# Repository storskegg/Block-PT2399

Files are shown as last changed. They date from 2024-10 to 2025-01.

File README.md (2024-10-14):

# Block-PT2399

A simple delay/echo design block based on the venerable PTC PT2399.

## Features

- Star Grounds: This board features a 2-star ground configuration
    1. All ground connections from and relating directly to the PT2399, and its
       dedicated power supply (`7805`) have their own trace to the negative lead
       on the `7805`'s `100uF` bypass capacitor.
    2. The above ground star, and all other ground connections (e.g. JFET
       impedance buffer) have their own traces back to `Sig_gnd`.
- Onboard regulation: The PT2399 is a particularly noisy beast, and must have
  its own power rail. As such, this board has its own 7805 regulator, and bypass
  capacitor (`100uF` located as close to the PT2399 as possible, while
  facilitating the star ground to the chip's supporting circuitry, and mfr's
  fabrication constraints.)

## Background

I've been working on a blues harp preamp for a buddy, and have been working on
the design in logical blocks that more or less get strung together. (It makes a
lot of sense when looking at valve gain stages, which are all basically the same
circuit repeated, maybe with different component values.) He mentioned wanting
delay or echo, and so I put this together. It is not a ground-up design, but
rather one that was inspired by the countless examples of using the PT2399
that you can find in the wild. (Sometimes it's better to stand on the shoulders
of giants.)

Anyhow, I decided to do up a board for ease of use in future projects.

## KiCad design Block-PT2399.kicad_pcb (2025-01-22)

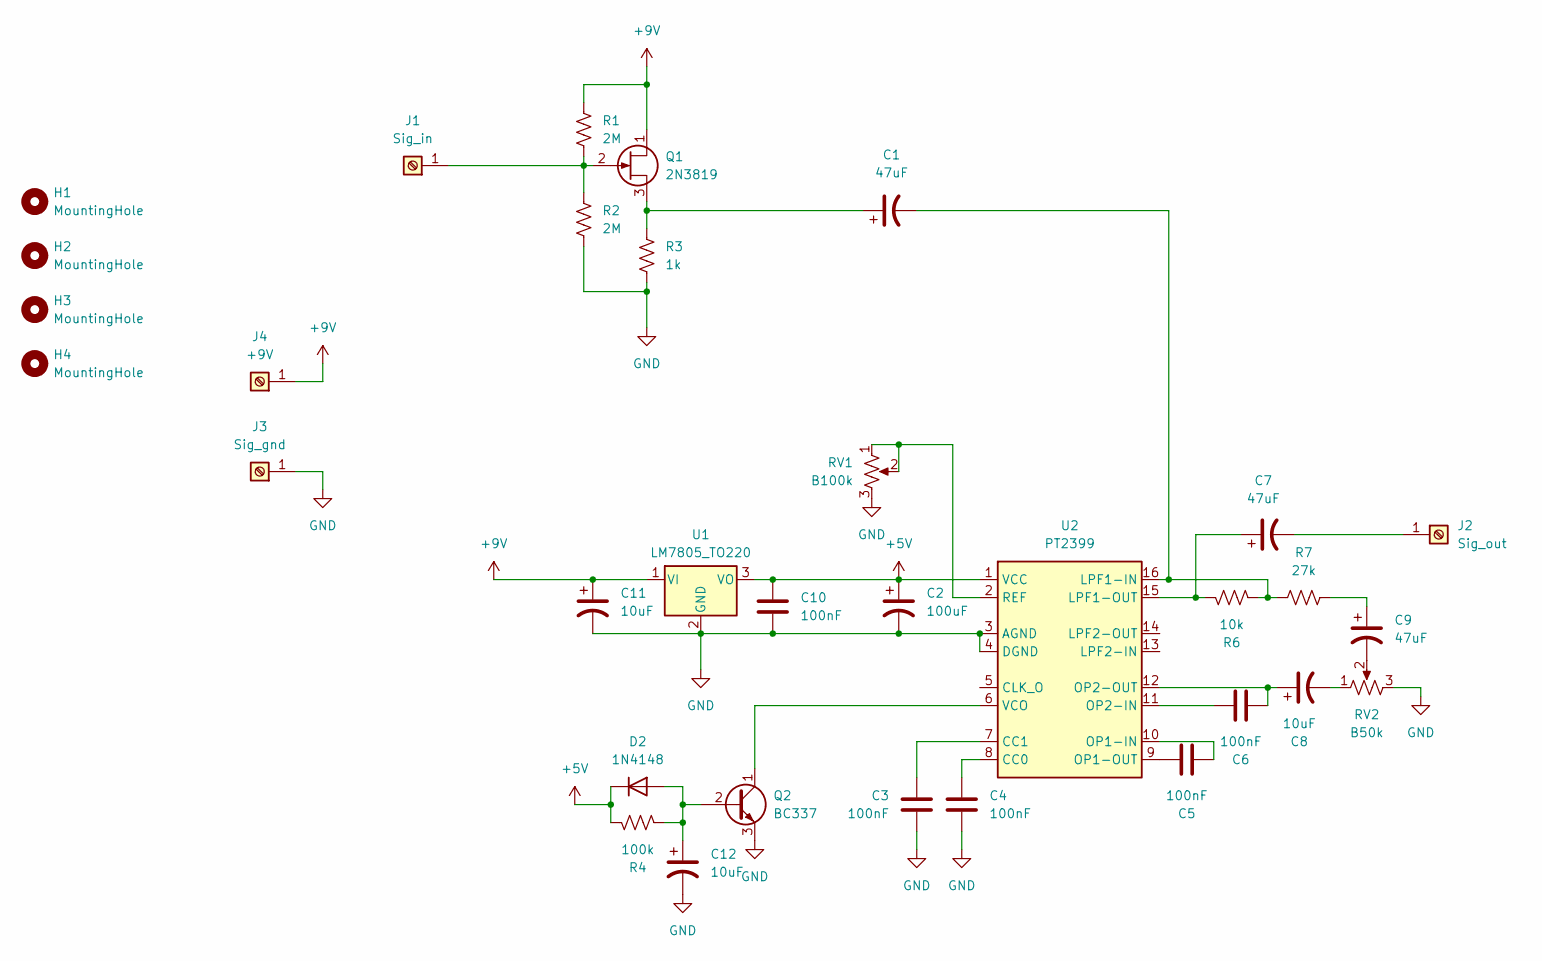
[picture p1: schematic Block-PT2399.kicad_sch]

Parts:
C1, C7, C9: 47uF; CP_Radial_D5.0mm_P2.00mm
C2: 100uF; CP_Radial_D5.0mm_P2.50mm
C3, C4, C5, C6: 100nF; C_Disc_D4.3mm_W1.9mm_P5.00mm
C8: 10uF; CP_Radial_D4.0mm_P1.50mm
C10: 100nF; C_Disc_D3.0mm_W1.6mm_P2.50mm
C11: 10uF; CP_Radial_D5.0mm_P2.00mm
C12: 10uF; CP_Radial_D4.0mm_P2.00mm
D2: 1N4148; D_DO-35_SOD27_P7.62mm_Horizontal
H1, H2, H3, H4: MountingHole; MountingHole_2.2mm_M2
J1: Sig_in; TerminalBlock_MetzConnect_360271_1x01_Horizontal_ScrewM3.0_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
J2: Sig_out; TerminalBlock_MetzConnect_360271_1x01_Horizontal_ScrewM3.0_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
J3: Sig_gnd; TerminalBlock_MetzConnect_360271_1x01_Horizontal_ScrewM3.0_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
J4: +9V; TerminalBlock_MetzConnect_360271_1x01_Horizontal_ScrewM3.0_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
Q1: 2N3819; TO-92_Inline_Wide
Q2: BC337; TO-92_Inline
R1, R2: 2M; R_Axial_DIN0207_L6.3mm_D2.5mm_P10.16mm_Horizontal
R3: 1k; R_Axial_DIN0207_L6.3mm_D2.5mm_P10.16mm_Horizontal
R4: 100k; R_Axial_DIN0204_L3.6mm_D1.6mm_P5.08mm_Horizontal
R6: 10k; R_Axial_DIN0207_L6.3mm_D2.5mm_P10.16mm_Horizontal
R7: 27k; R_Axial_DIN0207_L6.3mm_D2.5mm_P10.16mm_Horizontal
RV1: B100k; Potentiometer_Bourns_3266Y_Vertical
RV2: B50k; Potentiometer_Bourns_3266Y_Vertical
U1: LM7805_TO220; TO-220-3_Vertical
U2: PT2399; DIP-16_W7.62mm

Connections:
+5V: C2.1, C10.1, D2.1 (K), R4.2, U1.3 (VO), U2.1 (VCC)
+9V: C11.1, J4.1, Q1.1 (D), R1.1, U1.1 (VI)
GND: C2.2, C3.2, C4.2, C10.2, C11.2, C12.2, J3.1, Q2.3 (E), R2.2, R3.2, RV1.3, RV2.3, U1.2 (GND), U2.3 (AGND), U2.4 (DGND)
unnamed: C8.2, RV2.1
unnamed: C9.1, R7.2
unnamed: C9.2, RV2.2
unnamed: C12.1, D2.2 (A), Q2.2 (B), R4.1
unnamed: J1.1, Q1.2 (G), R1.2, R2.1
unnamed: C7.2, J2.1
unnamed: C1.1, Q1.3 (S), R3.1
unnamed: Q2.1 (C), U2.6 (VCO)
unnamed: C4.1, U2.8 (CC0)
unnamed: C3.1, U2.7 (CC1)
unnamed: C1.2, R6.2, R7.1, U2.16 (LPF1-IN)
unnamed: C7.1, R6.1, U2.15 (LPF1-OUT)
unnamed: C5.1, U2.10 (OP1-IN)
unnamed: C5.2, U2.9 (OP1-OUT)
unnamed: C6.1, U2.11 (OP2-IN)
unnamed: C6.2, C8.1, U2.12 (OP2-OUT)
unnamed: RV1.1, RV1.2, U2.2 (REF)

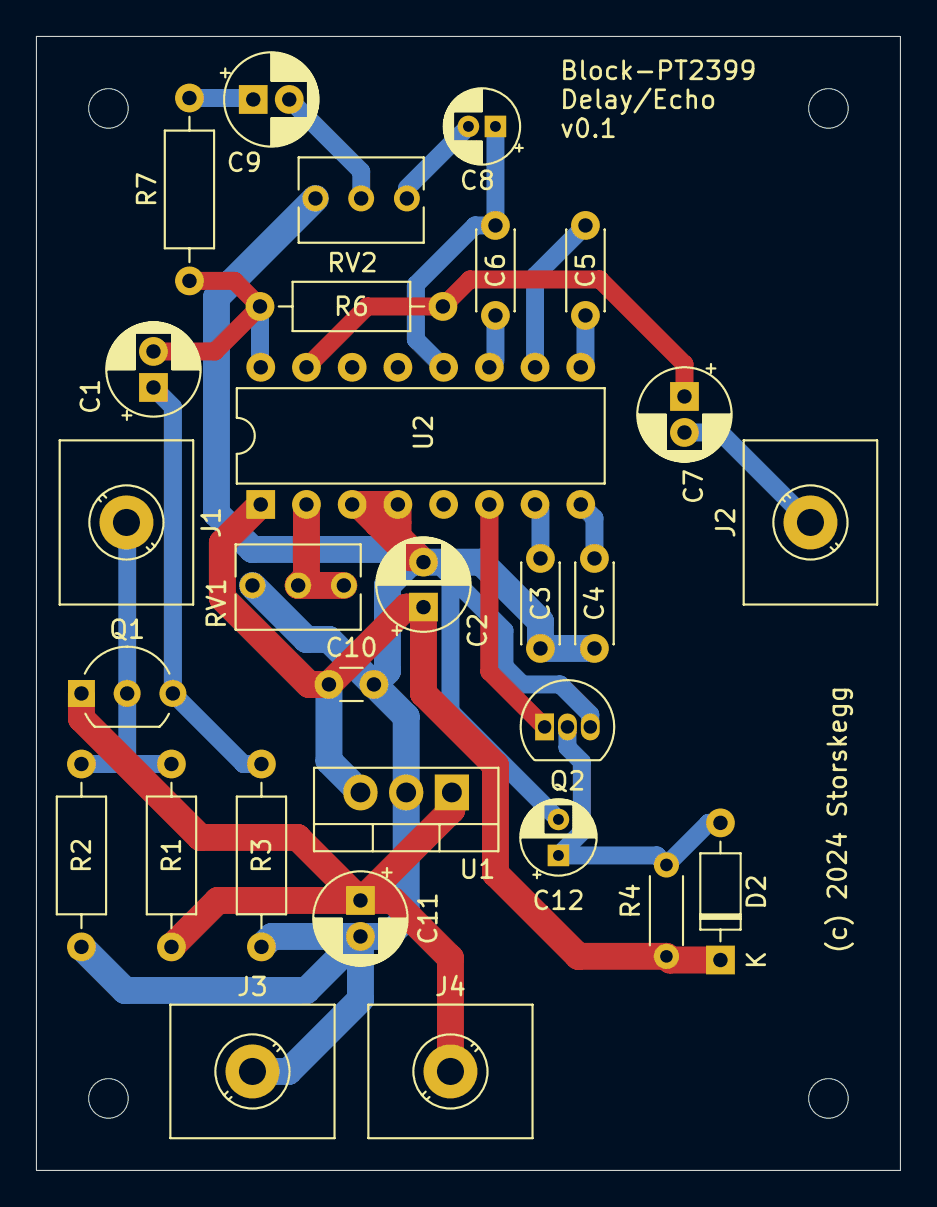
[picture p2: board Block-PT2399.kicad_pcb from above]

Board: 2 copper layers, 48.0 x 63.0 mm, 33 parts (0 on the bottom side), 20 nets.

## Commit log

2024-10-14 Add the project files
    [Block-PT2399-B_Cu.gbr, Block-PT2399-B_Mask.gbr, Block-PT2399-B_Paste.gbr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]
2024-10-18 implement pin-2 hack and anti-latch
    [Block-PT2399-B_Cu.gbr, Block-PT2399-B_Mask.gbr, Block-PT2399-B_Paste.gbr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]
2025-01-22 working on redoing board size and layout, dropped the diode
    [Block-PT2399.kicad_pcb, Block-PT2399.kicad_sch]
2025-01-22 widen traces to lower trace impedances
    [Block-PT2399.kicad_pcb]

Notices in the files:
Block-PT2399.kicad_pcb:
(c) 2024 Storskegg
